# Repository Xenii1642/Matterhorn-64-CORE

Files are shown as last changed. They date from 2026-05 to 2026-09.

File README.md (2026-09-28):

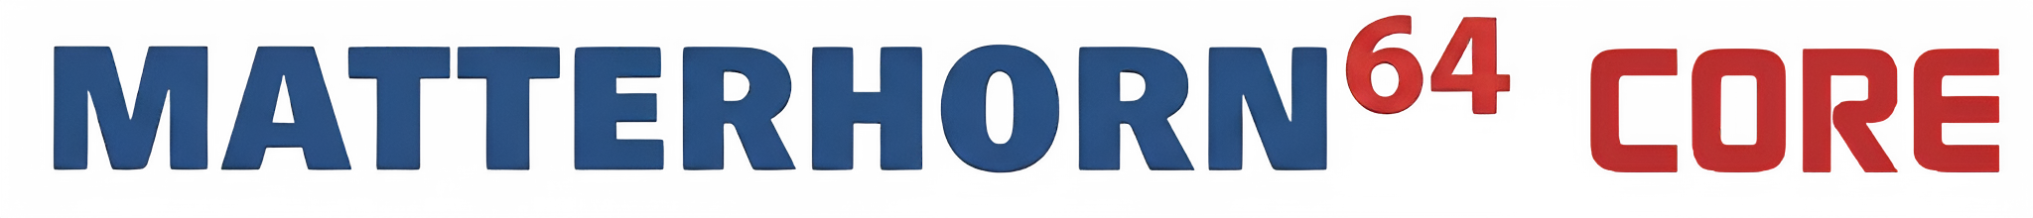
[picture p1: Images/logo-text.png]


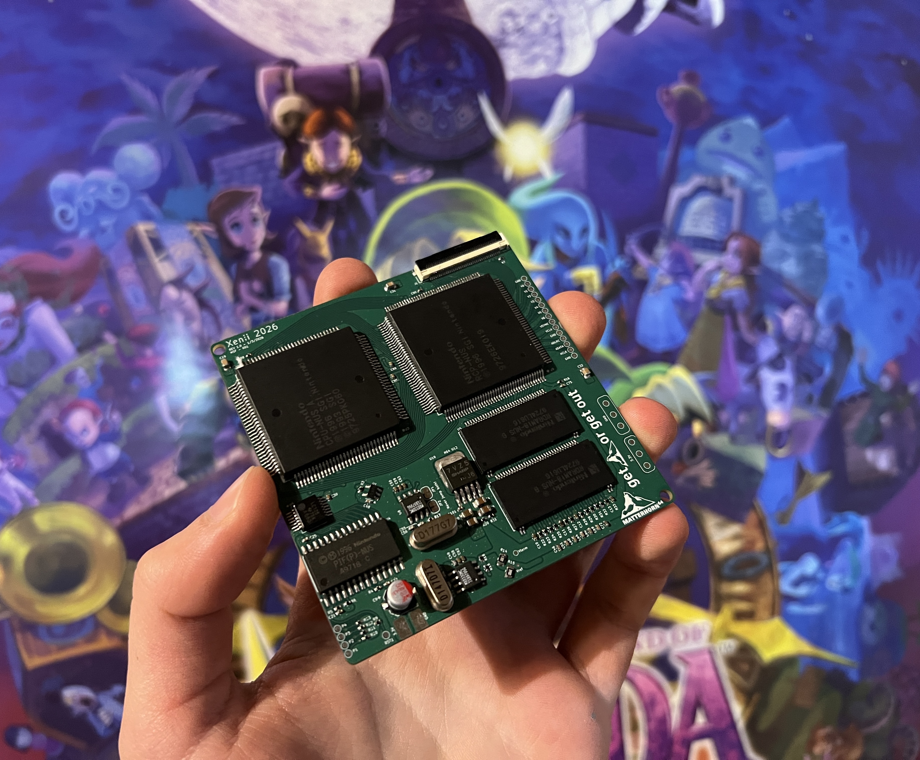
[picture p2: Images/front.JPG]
 
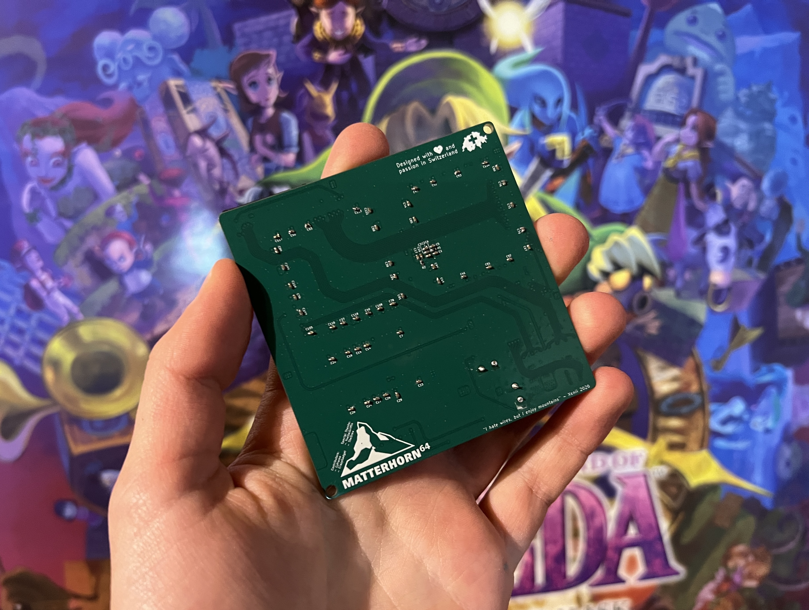
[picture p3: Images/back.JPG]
 



Matterhorn 64 CORE is the world's smallest open-source Nintendo 64 motherboard redesign. 
It utilizes components taken from an original Nintendo 64 console. 
Because it does **not** rely on emulation, it works perfectly with all games released on the system. 

This board redesign enables smaller, better, cleaner and more reliable Nintendo 64 based builds. 
Matterhorn 64 CORE can easily be integrated in different kinds of builds such as Nintendo 64 portable devices or mini consoles. 

It is fully open-source and released under the CERN-OHL-S-2.0 license. 

## Features
The Matterhorn 64 CORE redesign:
- The world's smallest open source Nintendo 64 motherboard
- Fits in a tiny 78x77.2 mm form factor 
- Runs on real hardware, **no emulation**
- 100% compatible with **all** games released on the system, including flashcarts
- Runs on 3.3V @2A 
- Designed using KiCad 9
- Layout and routing is optimized and clean, making it easy to use in future Nintendo 64 builds
- 100% open-source and released under the CERN-OHL-S-2.0 license

## Compatibility
### General compatibility
Due to the complexity of the Nintendo 64 hardware, some of its features are not available on this design. 
Please note that:
- The console is compatible with both NTSC and PAL components. However, it is **NOT** region free. It will only accept games released on the same region as the donor board.
- The console does accept memory expansion, but it is not natively compatible with the orignal Expansion Pak cartridge. You'll need to solder two RDRAM36 4MB instead of the two RDRAM18 2MB chips present by default on the console in order to enable the Expansion Pak.
- The console does **NOT** have any video output system. You'll either need to hook up an original composite encoder compatible with your region or an HDMI kit.
- The console does **NOT** have on-board voltage regulators. An additional N64 PSU or 3.3V PSU will be needed in order to use it. The console requires only requires 3.3V at 2A, but please consider that some HDMI mod or composite encoders may require 5V as well.
- The console is compatible with original controllers.
- It is also compatible with original cartridges using the breakout board.

### Nintendo 64 donor board revision compatibility
This mod is **ONLY** compatible with the following motherboard revisions:
#### NTSC Revisions (North America and Japan)
- NUS-CPU-01 (Japan only - 1996)
- NUS-CPU-02 (1996)
- NUS-CPU-03 (1996)
- NUS-CPU-04 (1996-1997)
- NUS-CPU-05 (1997)
- NUS-CPU-05-1 (1997)
- NUS-CPU-06 (1998)
- NUS-CPU-07 (1998)

#### PAL REVISION (Europe and Australia)
- NUS-CPU(P)-01 (1996)
- NUS-CPU(R)-01 (France only - 1997)

**ANY NEWER REVISION WILL NOT BE COMPATIBLE**

## Disclamer
This project requires complex soldering techniques. It relies on small pitch QFPs and 0402 passives.
Removing the components from the original board can cause irreparable damage if done incorrectly.

Due to the nature of this project, I am not responsible for any physical damages that may occur. 

## PCB Files
The Matterhorn 64 CORE motherboard has been entirely designed using KiCad 9. 
All the files are available in the [KiCad files folder](https://github.com/Xenii1642/Matterhorn-64-CORE/tree/main/KiCad%20Files) of this repository. 
The libraries created are also available in that same folder. 

Gerbers can be found in the [Gerber folder](https://github.com/Xenii1642/Matterhorn-64-CORE/tree/main/Gerbers). 

The console needs those two PCBs in order to make it work:
- [Matterhorn 64 CORE redesign](https://github.com/Xenii1642/Matterhorn-64-CORE/blob/main/Gerbers/Matterhorn-64-CORE.zip)
- [Matterhorn Cartridge Breakout](https://github.com/Xenii1642/Matterhorn-64-CORE/blob/main/Gerbers/Cartridge-Breakout-Board.zip)

The CORE itself represents the main logic of the console. The breakout board is used easily connect a full size game cartridge to the console. 

## Ordering
For this project, I recommend ordering the board through [JLCPCB](https://jlcpcb.com/) or [PCBWay](https://pcbway.com/). 
I personally ordered mine through [JLCPCB](https://jlcpcb.com/). 

You'll find here the list of settings that must be applied when ordering. 

### [Matterhorn 64 CORE](https://github.com/Xenii1642/Matterhorn-64-CORE/blob/main/Gerbers/Matterhorn-64-CORE.zip)
- Material: FR4
- Layers: 4
- Thickness: 1.6mm
- Specify Stackup: YES - JLC04161H-3313
- Impedance Control: ±10%
- Stencil: recommended but not obligatory.

### [Matterhorn Cartridge Breakout](https://github.com/Xenii1642/Matterhorn-64-CORE/blob/main/Gerbers/Cartridge-Breakout-Board.zip)
- Material: FR4
- Layers: 2

### Board Impedance Control
As you might notice, the CORE requires controlled impedance. 
The Nintendo 64 uses an extremely fast Rambus Dynamic Random Access Memory Bus (RDRAM BUS). 
In order to work, the CORE requires controlled impedance to match the 50Ω required by the RDRAM BUS. 

The Gerber files for this board include an Excel document which specifies which traces require those controlled impedance. 
This document will only be taken into account by JLCPCB if the order specifies the use of the "Controlled Impedance" option set to ±10%.

Please note that the board **might** work by using the 3313 stackup with no controlled impedance. 
To make sure my prototype was working, I did order it using those specifications. 
Ordering without it has not been tried and is at your own risks. 

All the components are listed in the Bill Of Materials (BOM). They can be ordered through Digikey or Mouser. 

## Assembly 
Once you've sourced a working Nintendo 64 console, a few games to test it, all the components and the Matterhorn 64 CORE boards, assembly can begin!
First of all, you'll need to access the Nintendo 64 motherboard and remove these components:
- CPU-NUS (U10)
- RCP-NUS (U9)
- 2x RDRAM18-NUS (U14 & U11) (or 1x RDRAM36 depending of the version, U14)) 
- NUS-PIF (U6)
- PTS9128 (U3)
- 74LCV125 (U8)
- 2x MX8330 (U7 & U15)
- 2x Crystals (X1 & X2)
- Sharp 7VZ5 LDO (U12)
- Cartridge slot (P5)

Source of this image: Wikipedia.com
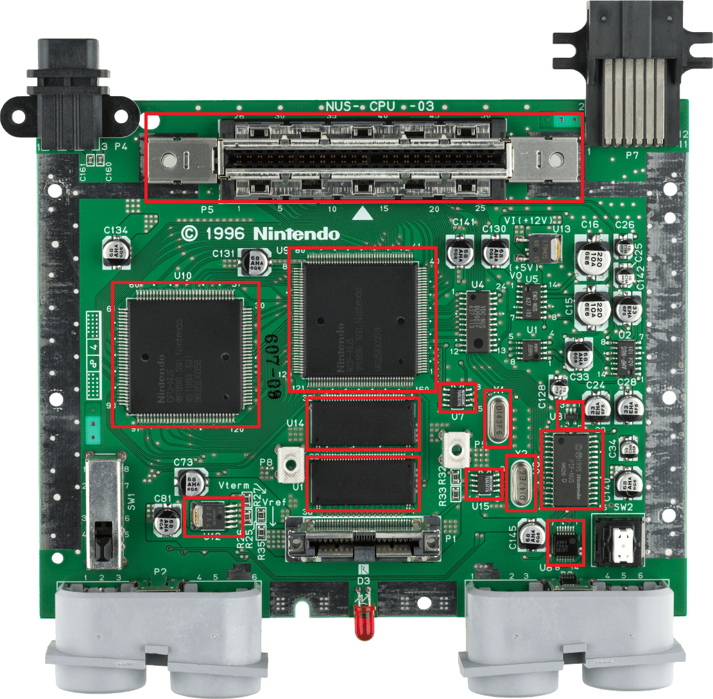
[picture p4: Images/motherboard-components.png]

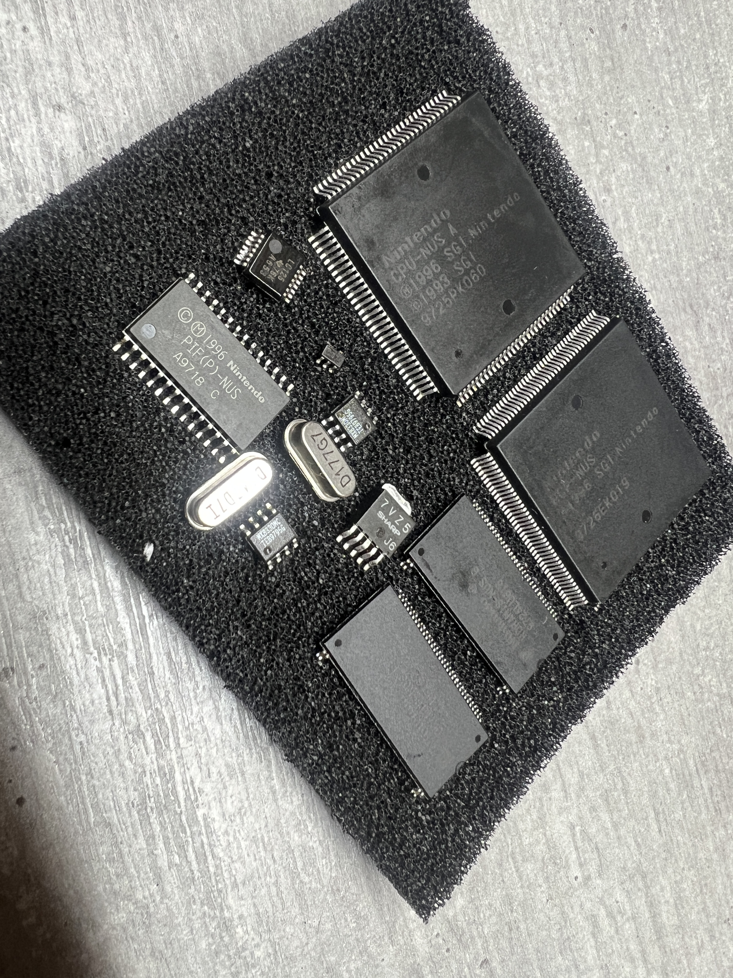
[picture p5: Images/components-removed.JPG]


I personally removed mine using hot air and a bit of flux. I heated at 360°C. 
Once removed, they can take place on the new motherboard. 
Low melting solder is not recommended in this process since the board will heat and cool down constantly when running, which can damage the solder joints after a long time. It is also not recommended to heat either the board or the components too much, which could lead to issues. 
I recommend soldering the whole front side and then solder the back side. 

The breakout board is much simpler, it only has a single FFC connector and the cartridge slot, which are much easier to solder than the little passives in my opinion. 

Once everything is done and cleaned using isopropyl alcohol, the test process can begin!

## Testing
First, connect the breakout board and make sure you don't have any dead shorts between the 3.3V line and the GND. 
Then, insert a game and power it up! The board is properly powered if:
- The console draws roughly 1.4A
- Vterm shows 2.55V
- Vref shows 1.91V

If you own a logic analyzer, you can connect it to the audio data pins or controller ports.
This is what you should see on the controller data line when a controller is plugged on Super Mario 64
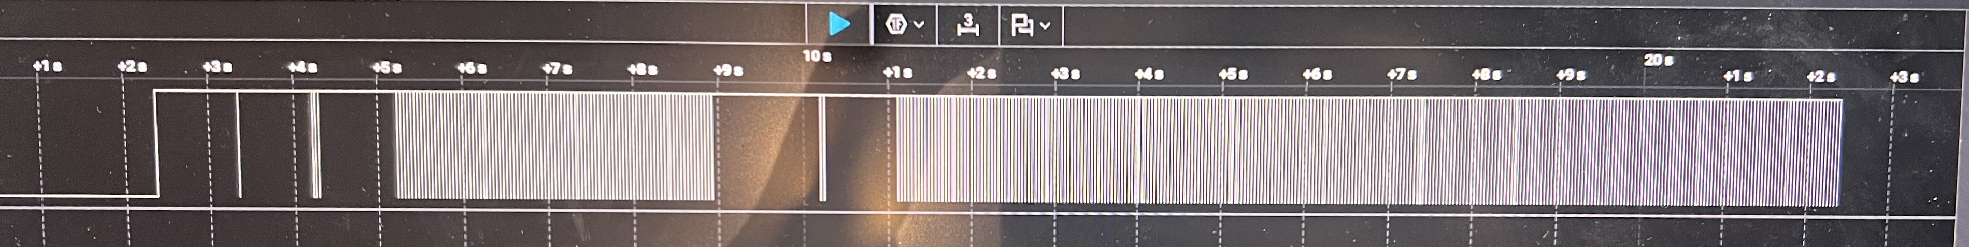
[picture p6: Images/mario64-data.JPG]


Please note that those signals **DO NOT** appear if the game is not properly read.
If everything seems good, you can hook up an HDMI mod or composite encoder and test it out! If it displays, it works! Great job!

## Known issue:
When I assembled my prototype, I *probably* heated the CPU too much while removing it. This caused the console to only work if heated.
More tests will be done to understand what exactly caused that. 

However I want to mention that the board works flawlessly for multiple consecutive days. 

## Future projects
This board is my official entry into Nintendo 64 modding. 
I'm working on two big projects which both use the CORE:
- Weisshorn 64 Mini: A collab between SenorAvocado and the Xii-Labs to create a Nintendo 64 Classic Mini console.
- Matterhorn 64: An ultimate Nintendo 64 portable. It's going to be a true revolution, also powered by the core.

Going to keep everyone update through my socials and the BitBuilt server. 

## Credits
This project was the most complicated I've done. Thankfully some members of the BitBuilt community helped me out to make my journey easier.
Therefore, I wanted to address big thanks to:
- @cy-888 who collaborated with me on some part of the design, especially footprints
- @CrazyGadgetMods who made great open-source flexes which helped me understanding some part of the console
- @mackieks who answered all my technical questions and took the time to review the whole board
- @thedrew and @gunnar who gave me insiparation to design my own motherboard recreation as long as helping me throughout the process.

## Media
You can find a video of my working board on my Instagram account:
[Matterhorn 64 CORE testing video](https://www.instagram.com/reel/DWvlAQKiPuf/)

I've also considered making a longer YouTube video on the subject. I will probably do it when I have more time.
## License
Matterhorn 64 CORE is released under the CERN-OHL-S-2.0 license. 
This license allows you to:
- Study
- Modify
- Manufacture
- Sell
- Distribute

Any modified versions of derivatives must also remain open-source under **the same, unmodified license**
You must also properly credit the original creators when reusing or redistributing these files.

## Support
If you notice anything wrong with the design, please let me know!
You can also reach to me for questions or general help, I'm always happy to help 👍

Thank you for your support and see you next time!

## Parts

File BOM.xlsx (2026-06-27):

Matterhorn 64 CORE BOM
CORE
Reference | Quantity | Value | Description | Manufacter Part Number | Link
C1,C2,C6,C17,C18,C19,C20 | 7 | 33µF | CAP TANT 33UF 10% 10V 1411 | TAJB336K010RNJ | https://www.digikey.com/en/products/detail/kyocera-avx/TAJB336K010RNJ/465808
C3,C12,C21,C23,C26,C27,C35, C38,C39,C41,C42,C43,C44,C45, C52,C53,C56,C57,C58,C61,C62, C70,C73,C80,C85,C86,C90,C92,C93 | 27 | 1µF | CAP CER 1UF 16V X5R 0402 | CL05A105KO5NNNC | https://www.digikey.com/en/products/detail/samsung-electro-mechanics/CL05A105KO5NNNC/3886725
C4,C5,C7,C8,C9,C11,C13,C25,C36, C37,C40,C47,C49,C50,C51,C54,C59, C60,C63,C64,C68,C69,C74,C75,C76, C77,C78,C79,C81,C82,C83,C87,C88, C89,C91,C94,C95,C96 | 38 | 0.1µF | CAP CER 0.1UF 25V X5R 0402 | CL05A104KA5NNNC | https://www.digikey.com/en/products/detail/samsung-electro-mechanics/CL05A104KA5NNNC/3886701
C10,C46,C48,C55,C71,C72,C84 | 7 | 0.01µF | CAP CER 10000PF 16V X7R 0402 | GRM155R71C103KA01D | https://www.digikey.com/en/products/detail/murata-electronics/GRM155R71C103KA01D/587215
C14 | 1 | 0.47µF | CAP CER 0.47UF 10V X5R 0402 | C0402X5R100-474KNE-CT | https://www.digikey.com/en/products/detail/venkel/C0402X5R100-474KNE-CT/14652959
C15,C16,C28,C34 | 4 | 38pF | CAP CER 39PF 50V C0G/NP0 0402 | C0402C390J5GACTU | https://www.digikey.com/en/products/detail/kemet/C0402C390J5GACTU/411020
C22 | 1 | 0.22µF | CAP CER 0.22UF 16V X7R 0402 | CL05B224KO5NNNC | https://www.digikey.com/en/products/detail/samsung-electro-mechanics/CL05B224KO5NNNC/3886834
C24 | 1 | 560pF | CAP CER 560PF 50V C0G/NP0 0402 | GRM1555C1H561JA01D | https://www.digikey.com/en/products/detail/murata-electronics/GRM1555C1H561JA01D/702503
C29 | 1 | 47µF | CAP ALUM 47UF 20% 6.3V SMD | UCL0J470MCL1GS | https://www.digikey.com/en/products/detail/nichicon/UCL0J470MCL1GS/2300235
C30,C31,C32,C33 | 4 | 3.3µF | CAP CER 3.3UF 4V X5R 0402 | C1005X5R0G335K050BB | https://www.digikey.com/en/products/detail/tdk-corporation/C1005X5R0G335K050BB/2443426
C65,C66 | 2 | 220pF | CAP CER 220PF 25V X7R 0402 | C0402X7R250-221KNE-CT | https://www.digikey.com/en/products/detail/venkel/C0402X7R250-221KNE-CT/14651555
C67 | 1 | 1nF | CAP CER 1000PF 50V X7R 0402 | C0402C102K5RACTU | https://www.digikey.com/en/products/detail/kemet/C0402C102K5RACTU/411034
J1 | 1 | 5051104091 | CONN FFC BOTTOM 40POS 0.5MM R/A | 5051104091 | https://www.digikey.com/en/products/detail/molex/5051104091/5254662
R1 | 1 | 1kΩ | RES 1K OHM 1% 1/16W 0402 | RC0402FR-131KL | https://www.digikey.com/en/products/detail/yageo/RC0402FR-131KL/13546623
R2,R8,R9,R27 | 4 | 47kΩ | RES 47K OHM 1% 1/16W 0402 | RC0402FR-0747KL | https://www.digikey.com/en/products/detail/yageo/RC0402FR-0747KL/726616
R3 | 1 | 24Ω 1% | RES 24 OHM 1% 1/16W 0402 | RC0402FR-0724RL | https://www.digikey.com/en/products/detail/yageo/RC0402FR-0724RL/5280933
R4 | 1 | 2kΩ | RES 2K OHM 5% 1/16W 0402 | RC0402JR-072KL | https://www.digikey.com/en/products/detail/yageo/RC0402JR-072KL/726434
R5 | 1 | 301Ω 1% | RES 301 OHM 1% 1/16W 0402 | RC0402FR-07301RL | https://www.digikey.com/en/products/detail/yageo/RC0402FR-07301RL/726591
R6 | 1 | 316Ω 1% | RES 316 OHM 1% 1/16W 0402 | RC0402FR-07316RL | https://www.digikey.com/en/products/detail/yageo/RC0402FR-07316RL/5280974
R7 | 1 | 5.12kΩ | RES 5.1K OHM 1% 1/16W 0402 | RC0402FR-135K1L | https://www.digikey.com/en/products/detail/yageo/RC0402FR-135K1L/14286364
R10 | 1 | 51kΩ | RES 51K OHM 5% 1/16W 0402 | RC0402JR-0751KL | https://www.digikey.com/en/products/detail/yageo/RC0402JR-0751KL/2827651
R11 | 1 | 150Ω 1% | RES 150 OHM 1% 1/16W 0402 | RC0402FR-13150RL | https://www.digikey.com/en/products/detail/yageo/RC0402FR-13150RL/13694105
R12,R25,R29,R30 | 4 | 750Ω | RES 750 OHM 1% 1/16W 0402 | RC0402FR-13750RL | https://www.digikey.com/en/products/detail/yageo/RC0402FR-13750RL/17021816
R13,R14,R15,R16,R17,R18,R19,R20, R21,R22,R23,R24 | 12 | 51Ω | RES 51 OHM 1% 1/16W 0402 | RC0402FR-0751RL | https://www.digikey.com/en/products/detail/yageo/RC0402FR-0751RL/726629
R26 | 1 | 130Ω 1% | RES 130 OHM 1% 1/8W 0805 | RC0805FR-07130RL | https://www.digikey.com/en/products/detail/yageo/RC0805FR-07130RL/727589
R28 | 1 | 33Ω 1% | RES 33 OHM 1% 1/16W 0402 | RC0402FR-0733RL | https://www.digikey.com/en/products/detail/yageo/RC0402FR-0733RL/726593
R31 | 1 | 390Ω 1% | RES 390 OHM 1% 1/8W 0805 | RC0805FR-07390RL | https://www.digikey.com/en/products/detail/yageo/RC0805FR-07390RL/727902
R32,R33 | 2 | 4.7Ω | RES 4.7 OHM 5% 1/16W 0402 | RC0402JR-074R7L | https://www.digikey.com/en/products/detail/yageo/RC0402JR-074R7L/726476
Cartridge Breakout Board
Reference | Quantity | Value | Description | Manufacter Part Number | Link
J1 | 1 |  | CONN FFC BOTTOM 40POS 0.5MM R/A | 5051104091 | https://www.digikey.com/en/products/detail/molex/5051104091/5254662
C1, C2 | 2 | 10µF | CAP CER 10UF 10V X5R 0402 | CL05A106MP5NUNC | https://www.digikey.com/en/products/detail/samsung-electro-mechanics/CL05A106MP5NUNC/3887108

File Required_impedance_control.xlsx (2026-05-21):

Name | Signal | Reference Layer | Impedance Type | Trace Width (mils) | Impedance trace to copper (mils) | Impedance(ohm)±10% | Position | Note
Rambus Dynamic RAM Data Traces TOP LAYER (RDRAM) TOP LAYER | L1 | L2 | Single Ended (Non Coplanar) | 6.16 mils (0.156464 mm) | - | 50 |  | Required stackup: JLC04161H-3313 All the selected layers (in white) require 50 Ohms of impedance. The TOP traces are single ended non coplanar, but the BOTTOM traces are coplanar. Feel free to reach out in case you need to confirm something. Thanks a lot!
Rambus Dynamic RAM Data Traces (RDRAM) BOTTOM LAYER | L4 | L3 | Single Ended (Coplanar) | 6.06 mils (0.1539 mm) | 11.81102 mils (0.3 mm) | 50
CCTLPGM | L1 | L2 | Single Ended (Coplanar) | 23.24 mils (0.5903 mm) | 11.81102 mils (0.3 mm) | 22 |  | This curved trace requires 22 Ohms of impedance.
Detailed RDRAM traces
Layer 1 |  |  | Layer 4 |  | Both Top and Bottom Layers

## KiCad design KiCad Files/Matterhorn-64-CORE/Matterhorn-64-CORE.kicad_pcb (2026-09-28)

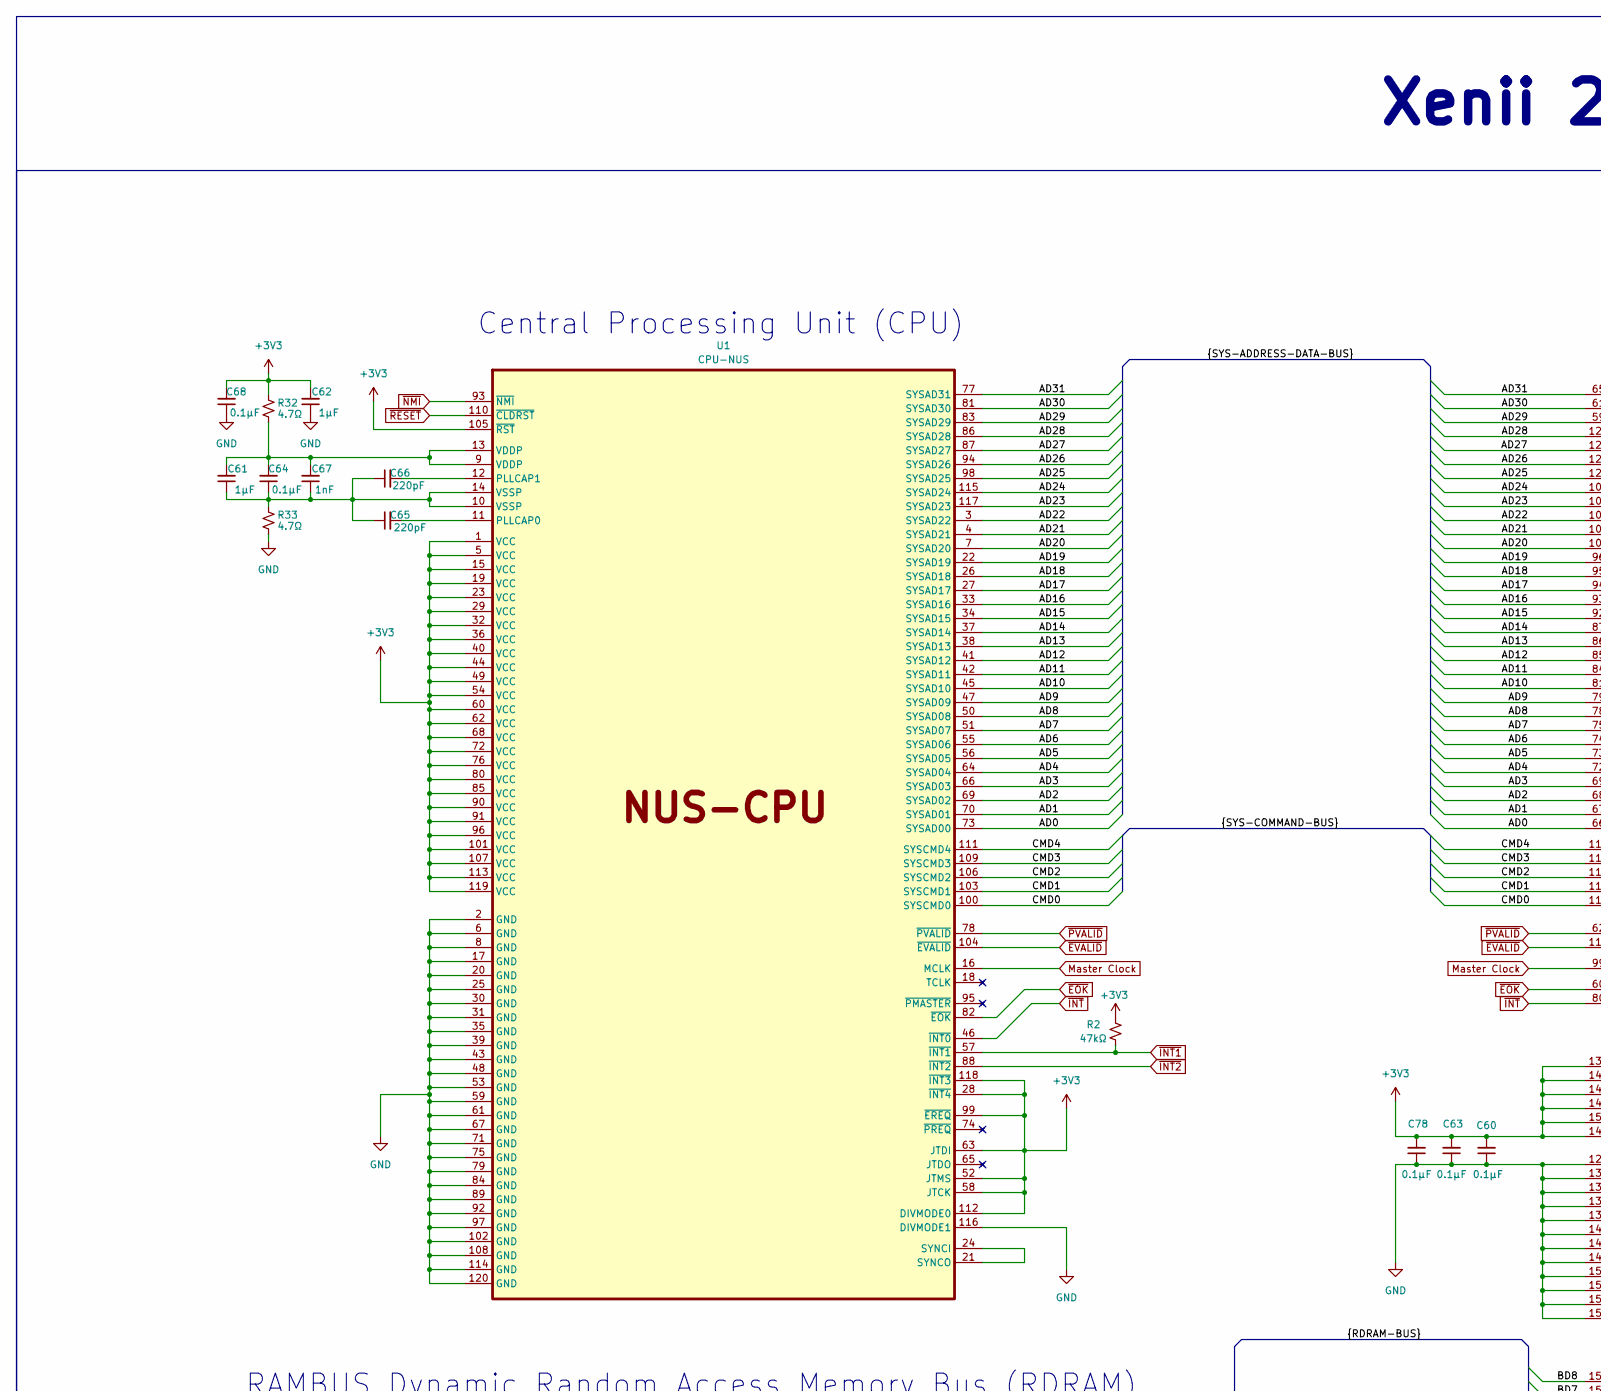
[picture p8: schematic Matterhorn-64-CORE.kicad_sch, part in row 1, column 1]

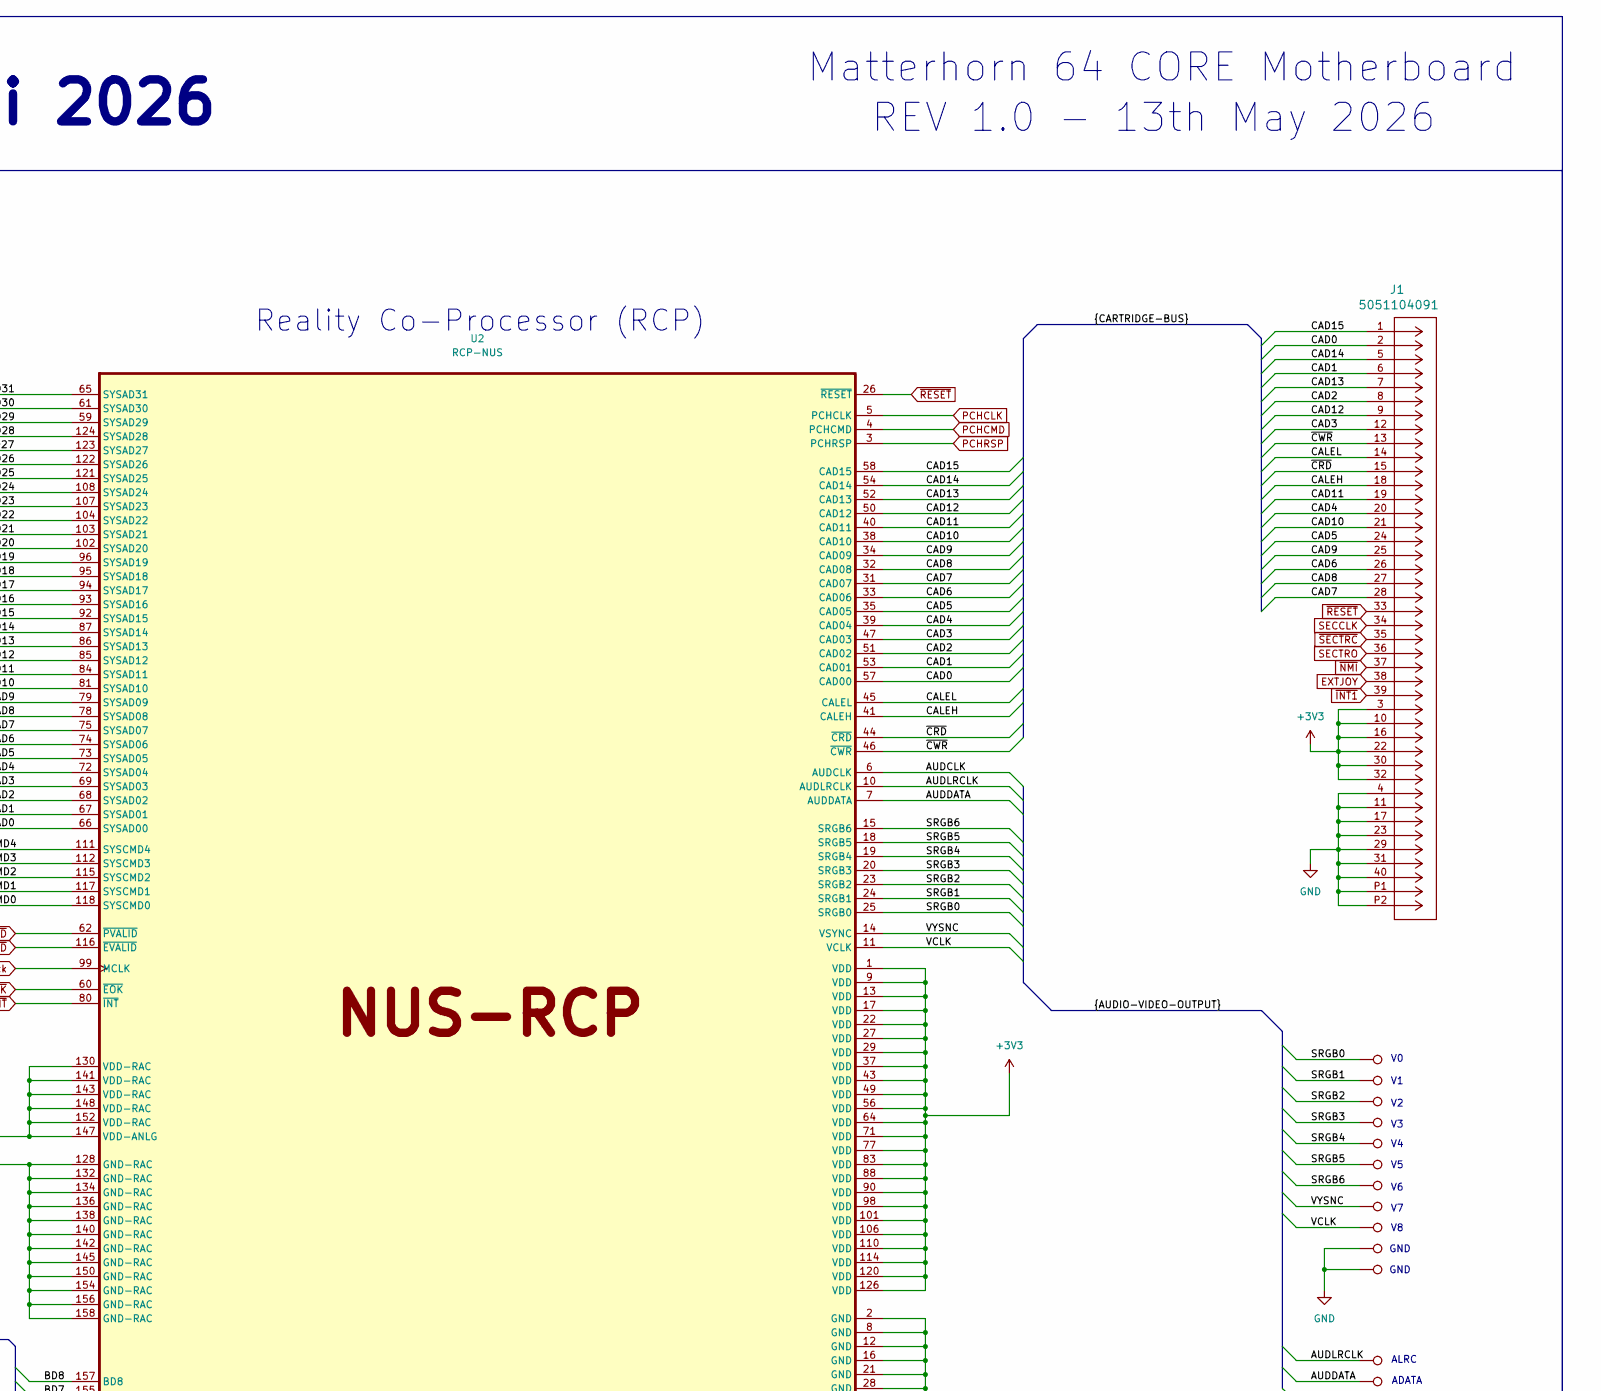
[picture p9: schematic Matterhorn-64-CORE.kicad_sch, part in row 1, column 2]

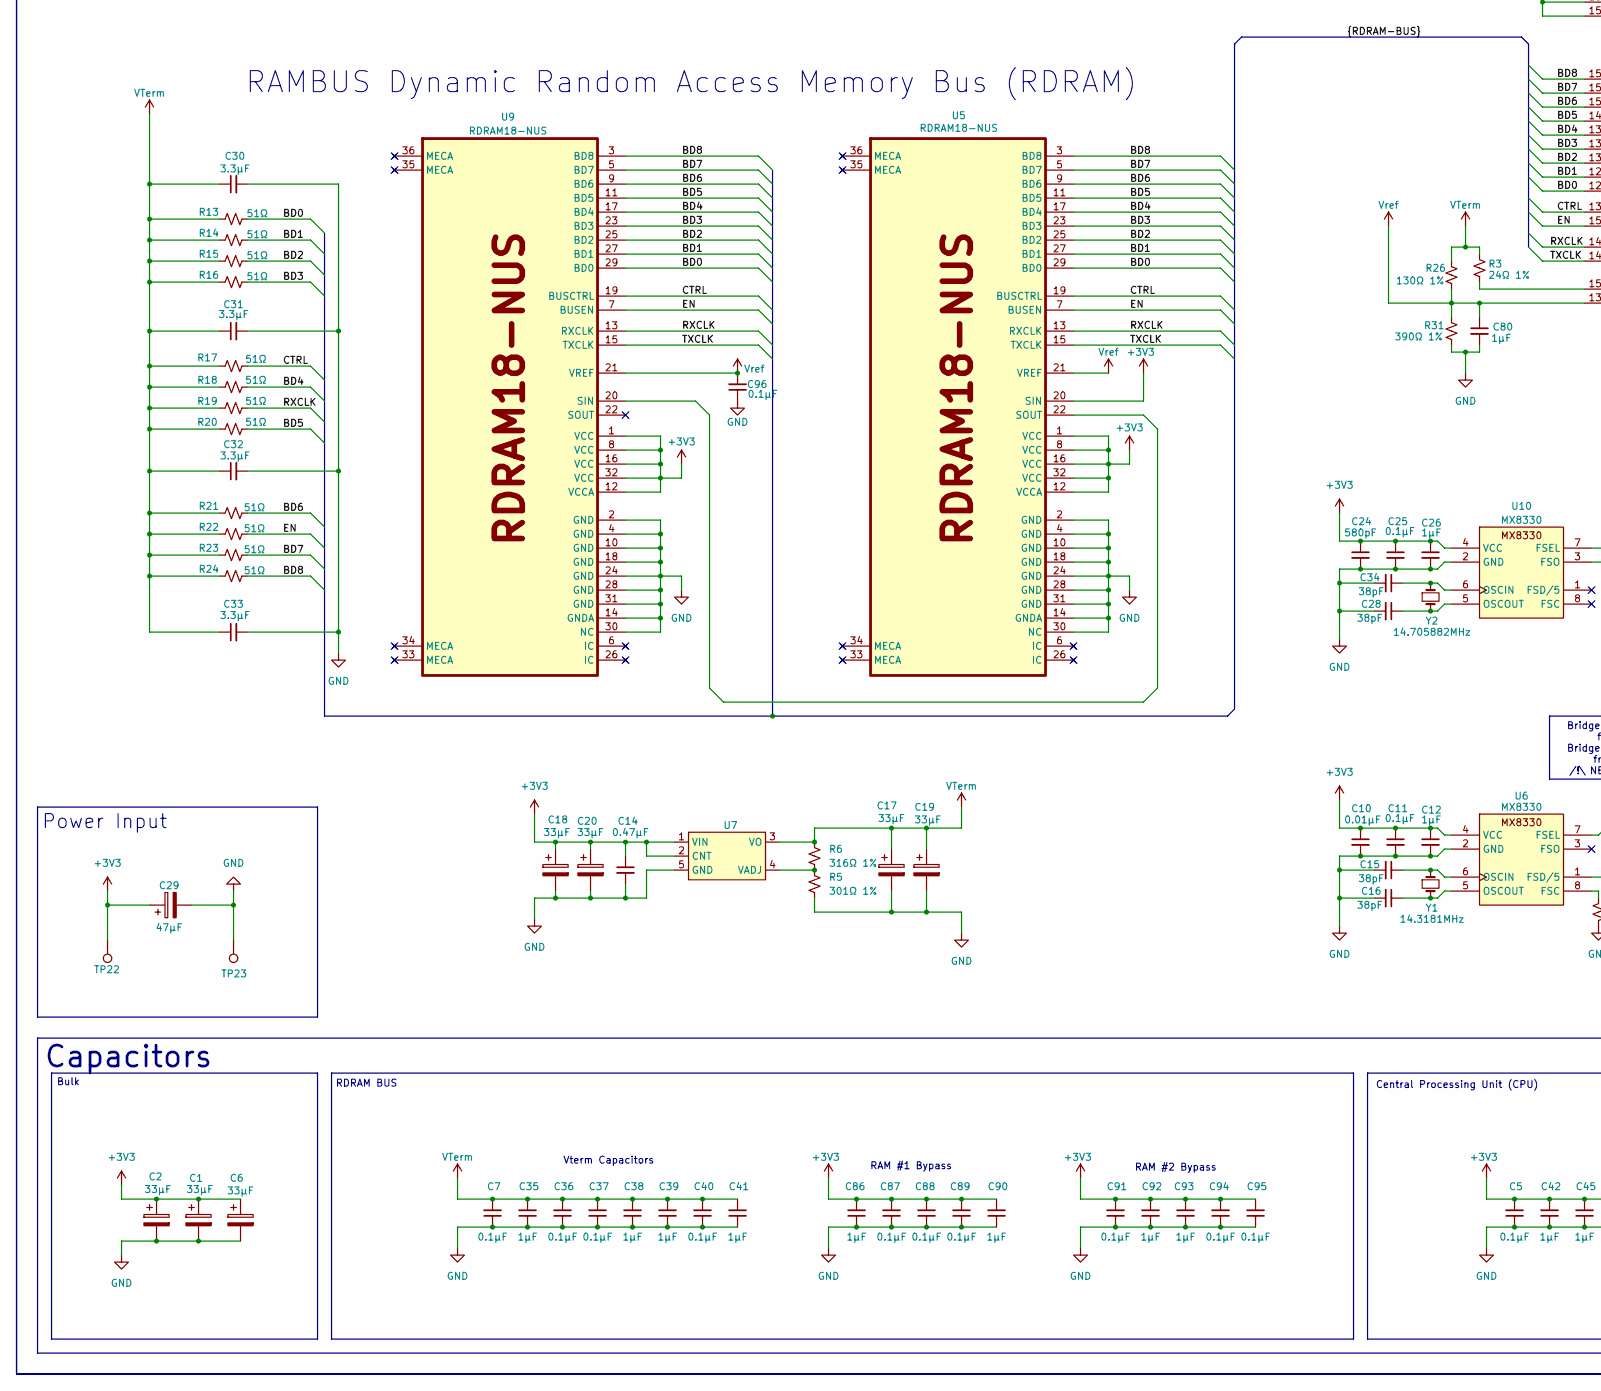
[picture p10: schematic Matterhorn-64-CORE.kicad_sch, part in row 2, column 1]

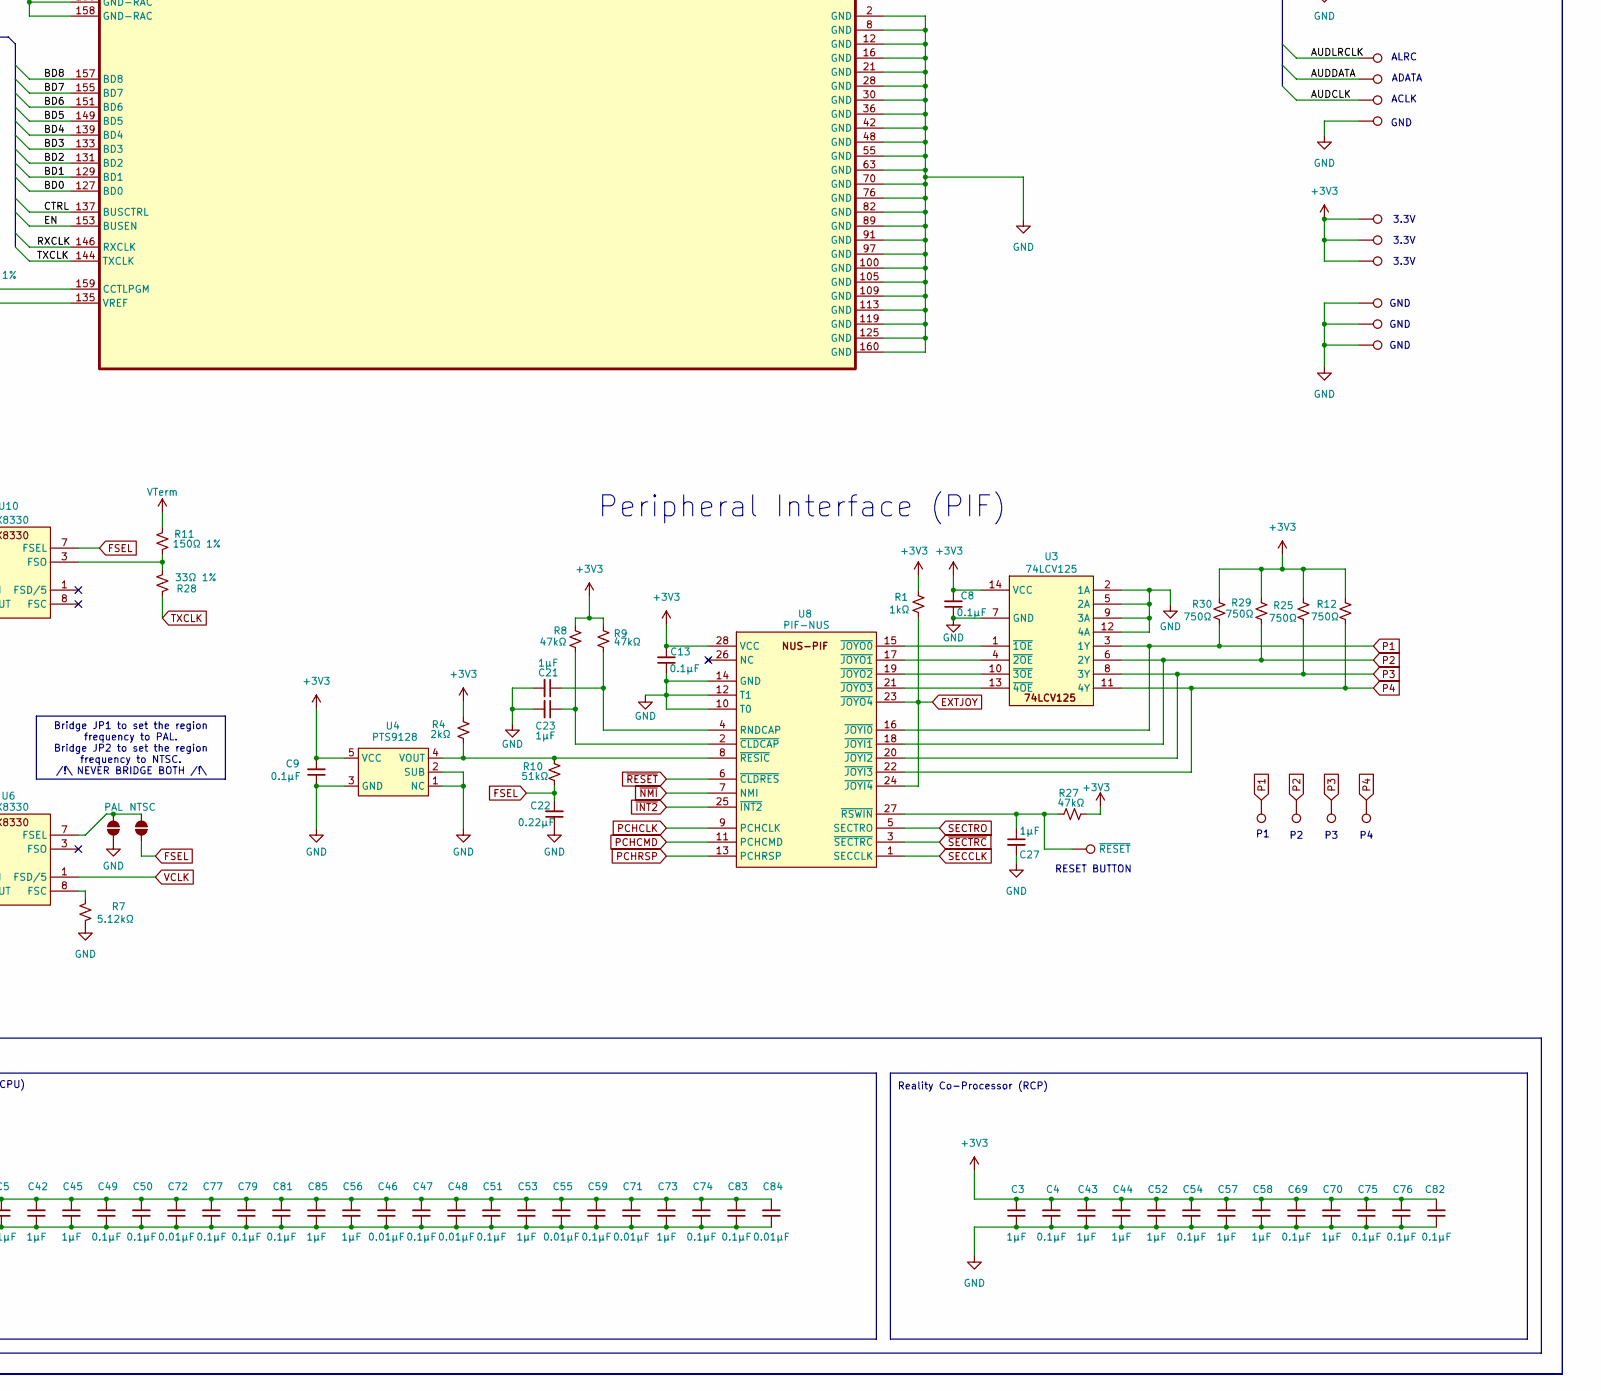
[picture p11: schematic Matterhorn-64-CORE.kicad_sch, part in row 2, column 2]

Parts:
C1, C2, C6, C17, C18, C19, C20: 33µF; TAJB_AVX-M
C3, C12, C21, C23, C26, C27, C35, C38, C39, C41, C42, C43, C44, C45, C52, C53, C56, C57, C58, C61, C62, C70, C73, C80, C85, C86, C90, C92, C93: 1µF; C_0402_1005Metric
C4, C5, C7, C8, C9, C11, C13, C25, C36, C37, C40, C47, C49, C50, C51, C54, C59, C60, C63, C64, C68, C69, C74, C75, C76, C77, C78, C79, C81, C82, C83, C87, C88, C89, C91, C94, C95, C96: 0.1µF; C_0402_1005Metric
C10, C46, C48, C55, C71, C72, C84: 0.01µF; C_0402_1005Metric
C14: 0.47µF; C_0402_1005Metric
C15, C16, C28, C34: 38pF; C_0402_1005Metric
C22: 0.22µF; C_0402_1005Metric
C24: 580pF; C_0402_1005Metric
C29: 47µF; 865080442004
C30, C31, C32, C33: 3.3µF; C_0402_1005Metric
C65, C66: 220pF; C_0402_1005Metric
C67: 1nF; C_0402_1005Metric
J1: 5051104091; CON_5051104091_MOL
NTSC: NTSC; SolderJumper-2_P1.3mm_Open_RoundedPad1.0x1.5mm
PAL: PAL; SolderJumper-2_P1.3mm_Open_RoundedPad1.0x1.5mm
R1: 1kΩ; R_0402_1005Metric
R2, R8, R9, R27: 47kΩ; R_0402_1005Metric
R3: 24Ω 1%; R_0402_1005Metric
R4: 2kΩ; R_0402_1005Metric
R5: 301Ω 1%; R_0402_1005Metric
R6: 316Ω 1%; R_0402_1005Metric
R7: 5.12kΩ; R_0402_1005Metric
R10: 51kΩ; R_0402_1005Metric
R11: 150Ω 1%; R_0402_1005Metric
R12, R25, R29, R30: 750Ω; R_0402_1005Metric
R13, R14, R15, R16, R17, R18, R19, R20, R21, R22, R23, R24: 51Ω; R_0402_1005Metric
R26: 130Ω 1%; R_0805_2012Metric
R28: 33Ω 1%; R_0402_1005Metric
R31: 390Ω 1%; R_0805_2012Metric
R32, R33: 4.7Ω; R_0402_1005Metric
RST1, RST2, RST3, RST4: TestPoint; TestPoint_Pad_D1.0mm
TP1, TP2, TP3, TP4, TP5, TP6, TP7, TP8, TP9, TP10, TP11, TP12, TP13, TP14, TP15, TP16, TP17, TP18, TP19, TP20, TP21: TestPoint; TestPoint_Pad_D1.0mm
TP22, TP23: TestPoint; PowerPad
U1: CPU-NUS
U2: RCP-NUS
U3: 74LCV125
U4: PTS9128; SOT-23-5
U5, U9: RDRAM18-NUS
U6, U10: MX8330
U7: SHARP 7VZ5
U8: PIF-NUS
Y1: 14.3181MHz; Crystal
Y2: 14.705882MHz; Crystal
~{RESET}: TestPoint; TestPoint_Pad_D1.0mm

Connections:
+3V3: C1.1, C2.1, C3.2, C4.2, C5.2, C6.1, C8.2, C9.2, C10.1, C11.1, C12.1, C13.2, C14.1, C18.1, C20.1, C24.1, C25.1, C26.1, C29.1, C42.2, C43.2, C44.2, C45.2, C46.2, C47.2, C48.2, C49.2, C50.2, C51.2, C52.2, C53.2, C54.2, C55.2, C56.2, C57.2, C58.2, C59.2, C60.2, C62.2, C63.2, C68.2, C69.2, C70.2, C71.2, C72.2, C73.2, C74.2, C75.2, C76.2, C77.2, C78.2, C79.2, C81.2, C82.2, C83.2, C84.2, C85.2, C86.2, C87.2, C88.2, C89.2, C90.2, C91.2, C92.2, C93.2, C94.2, C95.2, J1.3, J1.10, J1.16, J1.22, J1.30, J1.32, R1.1, R2.1, R4.2, R8.2, R9.2, R12.1, R25.1, R27.1, R29.1, R30.1, R32.1, TP19.1, TP20.1, TP21.1, TP22.1, U1.1 (VCC), U1.5 (VCC), U1.15 (VCC), U1.19 (VCC), U1.23 (VCC), U1.28 (~INT4), U1.29 (VCC), U1.32 (VCC), U1.36 (VCC), U1.40 (VCC), U1.44 (VCC), U1.49 (VCC), U1.52 (JTMS), U1.54 (VCC), U1.58 (JTCK), U1.60 (VCC), U1.62 (VCC), U1.63 (JTDI), U1.68 (VCC), U1.72 (VCC), U1.76 (VCC), U1.80 (VCC), U1.85 (VCC), U1.90 (VCC), U1.91 (VCC), U1.96 (VCC), U1.99 (~EREQ), U1.101 (VCC), U1.105 (~RST), U1.107 (VCC), U1.112 (DIVMODE0), U1.113 (VCC), U1.118 (~INT3), U1.119 (VCC), U2.1 (VDD), U2.9 (VDD), U2.13 (VDD), U2.17 (VDD), U2.22 (VDD), U2.27 (VDD), U2.29 (VDD), U2.37 (VDD), U2.43 (VDD), U2.49 (VDD), U2.56 (VDD), U2.64 (VDD), U2.71 (VDD), U2.77 (VDD), U2.83 (VDD), U2.88 (VDD), U2.90 (VDD), U2.98 (VDD), U2.101 (VDD), U2.106 (VDD), U2.110 (VDD), U2.114 (VDD), U2.120 (VDD), U2.126 (VDD), U2.130 (VDD-RAC), U2.141 (VDD-RAC), U2.143 (VDD-RAC), U2.147 (VDD-ANLG), U2.148 (VDD-RAC), U2.152 (VDD-RAC), U3.14 (VCC), U4.5 (VCC), U5.1 (VCC), U5.8 (VCC), U5.12 (VCCA), U5.16 (VCC), U5.20 (SIN), U5.32 (VCC), U6.4 (VCC), U7.1 (VIN), U7.2 (CNT), U8.28 (VCC), U9.1 (VCC), U9.8 (VCC), U9.12 (VCCA), U9.16 (VCC), U9.32 (VCC), U10.4 (VCC)
/AD0: U1.73 (SYSAD00), U2.66 (SYSAD00)
/AD1: U1.70 (SYSAD01), U2.67 (SYSAD01)
/AD2: U1.69 (SYSAD02), U2.68 (SYSAD02)
/AD3: U1.66 (SYSAD03), U2.69 (SYSAD03)
/AD4: U1.64 (SYSAD04), U2.72 (SYSAD04)
/AD5: U1.56 (SYSAD05), U2.73 (SYSAD05)
/AD6: U1.55 (SYSAD06), U2.74 (SYSAD06)
/AD7: U1.51 (SYSAD07), U2.75 (SYSAD07)
/AD8: U1.50 (SYSAD08), U2.78 (SYSAD08)
/AD9: U1.47 (SYSAD09), U2.79 (SYSAD09)
/AD10: U1.45 (SYSAD10), U2.81 (SYSAD10)
/AD11: U1.42 (SYSAD11), U2.84 (SYSAD11)
/AD12: U1.41 (SYSAD12), U2.85 (SYSAD12)
/AD13: U1.38 (SYSAD13), U2.86 (SYSAD13)
/AD14: U1.37 (SYSAD14), U2.87 (SYSAD14)
/AD15: U1.34 (SYSAD15), U2.92 (SYSAD15)
/AD16: U1.33 (SYSAD16), U2.93 (SYSAD16)
/AD17: U1.27 (SYSAD17), U2.94 (SYSAD17)
/AD18: U1.26 (SYSAD18), U2.95 (SYSAD18)
/AD19: U1.22 (SYSAD19), U2.96 (SYSAD19)
/AD20: U1.7 (SYSAD20), U2.102 (SYSAD20)
/AD21: U1.4 (SYSAD21), U2.103 (SYSAD21)
/AD22: U1.3 (SYSAD22), U2.104 (SYSAD22)
/AD23: U1.117 (SYSAD23), U2.107 (SYSAD23)
/AD24: U1.115 (SYSAD24), U2.108 (SYSAD24)
/AD25: U1.98 (SYSAD25), U2.121 (SYSAD25)
/AD26: U1.94 (SYSAD26), U2.122 (SYSAD26)
/AD27: U1.87 (SYSAD27), U2.123 (SYSAD27)
/AD28: U1.86 (SYSAD28), U2.124 (SYSAD28)
/AD29: U1.83 (SYSAD29), U2.59 (SYSAD29)
/AD30: U1.81 (SYSAD30), U2.61 (SYSAD30)
/AD31: U1.77 (SYSAD31), U2.65 (SYSAD31)
/AUDCLK: TP14.1, U2.6 (AUDCLK)
/AUDDATA: TP13.1, U2.7 (AUDDATA)
/AUDLRCLK: TP12.1, U2.10 (AUDLRCLK)
/BD0: R13.1, U2.127 (BD0), U5.29 (BD0), U9.29 (BD0)
/BD1: R14.1, U2.129 (BD1), U5.27 (BD1), U9.27 (BD1)
/BD2: R15.1, U2.131 (BD2), U5.25 (BD2), U9.25 (BD2)
/BD3: R16.1, U2.133 (BD3), U5.23 (BD3), U9.23 (BD3)
/BD4: R18.1, U2.139 (BD4), U5.17 (BD4), U9.17 (BD4)
/BD5: R20.1, U2.149 (BD5), U5.11 (BD5), U9.11 (BD5)
/BD6: R21.1, U2.151 (BD6), U5.9 (BD6), U9.9 (BD6)
/BD7: R23.1, U2.155 (BD7), U5.5 (BD7), U9.5 (BD7)
/BD8: R24.1, U2.157 (BD8), U5.3 (BD8), U9.3 (BD8)
/CAD0: J1.2, U2.57 (CAD00)
/CAD1: J1.6, U2.53 (CAD01)
/CAD2: J1.8, U2.51 (CAD02)
/CAD3: J1.12, U2.47 (CAD03)
/CAD4: J1.20, U2.39 (CAD04)
/CAD5: J1.24, U2.35 (CAD05)
/CAD6: J1.26, U2.33 (CAD06)
/CAD7: J1.28, U2.31 (CAD07)
/CAD8: J1.27, U2.32 (CAD08)
/CAD9: J1.25, U2.34 (CAD09)
/CAD10: J1.21, U2.38 (CAD10)
/CAD11: J1.19, U2.40 (CAD11)
/CAD12: J1.9, U2.50 (CAD12)
/CAD13: J1.7, U2.52 (CAD13)
/CAD14: J1.5, U2.54 (CAD14)
/CAD15: J1.1, U2.58 (CAD15)
/CALEH: J1.18, U2.41 (CALEH)
/CALEL: J1.14, U2.45 (CALEL)
/CMD0: U1.100 (SYSCMD0), U2.118 (SYSCMD0)
/CMD1: U1.103 (SYSCMD1), U2.117 (SYSCMD1)
/CMD2: U1.106 (SYSCMD2), U2.115 (SYSCMD2)
/CMD3: U1.109 (SYSCMD3), U2.112 (SYSCMD3)
/CMD4: U1.111 (SYSCMD4), U2.111 (SYSCMD4)
/CTRL: R17.1, U2.137 (BUSCTRL), U5.19 (BUSCTRL), U9.19 (BUSCTRL)
/EN: R22.1, U2.153 (BUSEN), U5.7 (BUSEN), U9.7 (BUSEN)
/RXCLK: R19.1, U2.146 (RXCLK), U5.13 (RXCLK), U9.13 (RXCLK)
/SRGB0: TP2.1, U2.25 (SRGB0)
/SRGB1: TP3.1, U2.24 (SRGB1)
/SRGB2: TP4.1, U2.23 (SRGB2)
/SRGB3: TP5.1, U2.20 (SRGB3)
/SRGB4: TP6.1, U2.19 (SRGB4)
/SRGB5: TP7.1, U2.18 (SRGB5)
/SRGB6: TP8.1, U2.15 (SRGB6)
/VYSNC: TP9.1, U2.14 (VSYNC)
/~CRD: J1.15, U2.44 (~CRD)
/~CWR: J1.13, U2.46 (~CWR)
EXTJOY: J1.38, R1.2, U8.23 (~JOYO4), U8.24 (~JOYI4)
FSEL: C22.2, NTSC.1 (A), R10.1, U10.7 (FSEL)
GND: C1.2, C2.2, C3.1, C4.1, C5.1, C6.2, C7.1, C8.1, C9.1, C10.2, C11.2, C12.2, C13.1, C14.2, C15.2, C16.2, C17.2, C18.2, C19.2, C20.2, C21.2, C22.1, C23.2, C24.2, C25.2, C26.2, C27.2, C28.2, C29.2, C30.2, C31.2, C32.2, C33.2, C34.2, C35.1, C36.1, C37.1, C38.1, C39.1, C40.1, C41.1, C42.1, C43.1, C44.1, C45.1, C46.1, C47.1, C48.1, C49.1, C50.1, C51.1, C52.1, C53.1, C54.1, C55.1, C56.1, C57.1, C58.1, C59.1, C60.1, C62.1, C63.1, C68.1, C69.1, C70.1, C71.1, C72.1, C73.1, C74.1, C75.1, C76.1, C77.1, C78.1, C79.1, C80.2, C81.1, C82.1, C83.1, C84.1, C85.1, C86.1, C87.1, C88.1, C89.1, C90.1, C91.1, C92.1, C93.1, C94.1, C95.1, C96.1, J1.4, J1.11, J1.17, J1.23, J1.29, J1.31, J1.40, J1.P1, J1.P2, PAL.1 (A), R5.2, R7.2, R31.1, R33.2, TP1.1, TP11.1, TP15.1, TP16.1, TP17.1, TP18.1, TP23.1, U1.2 (GND), U1.6 (GND), U1.8 (GND), U1.17 (GND), U1.20 (GND), U1.25 (GND), U1.30 (GND), U1.31 (GND), U1.35 (GND), U1.39 (GND), U1.43 (GND), U1.48 (GND), U1.53 (GND), U1.59 (GND), U1.61 (GND), U1.67 (GND), U1.71 (GND), U1.75 (GND), U1.79 (GND), U1.84 (GND), U1.89 (GND), U1.92 (GND), U1.97 (GND), U1.102 (GND), U1.108 (GND), U1.114 (GND), U1.116 (DIVMODE1), U1.120 (GND), U2.2 (GND), U2.8 (GND), U2.12 (GND), U2.16 (GND), U2.21 (GND), U2.28 (GND), U2.30 (GND), U2.36 (GND), U2.42 (GND), U2.48 (GND), U2.55 (GND), U2.63 (GND), U2.70 (GND), U2.76 (GND), U2.82 (GND), U2.89 (GND), U2.91 (GND), U2.97 (GND), U2.100 (GND), U2.105 (GND), U2.109 (GND), U2.113 (GND), U2.119 (GND), U2.125 (GND), U2.128 (GND-RAC), U2.132 (GND-RAC), U2.134 (GND-RAC), U2.136 (GND-RAC), U2.138 (GND-RAC), U2.140 (GND-RAC), U2.142 (GND-RAC), U2.145 (GND-RAC), U2.150 (GND-RAC), U2.154 (GND-RAC), U2.156 (GND-RAC), U2.158 (GND-RAC), U2.160 (GND), U3.2 (1A), U3.5 (2A), U3.7 (GND), U3.9 (3A), U3.12 (4A), U4.1 (NC), U4.2 (SUB), U4.3 (GND), U5.2 (GND), U5.4 (GND), U5.10 (GND), U5.14 (GNDA), U5.18 (GND), U5.24 (GND), U5.28 (GND), U5.30 (NC), U5.31 (GND), U6.2 (GND), U7.5 (GND), U8.10 (T0), U8.12 (T1), U8.14 (GND), U9.2 (GND), U9.4 (GND), U9.10 (GND), U9.14 (GNDA), U9.18 (GND), U9.24 (GND), U9.28 (GND), U9.30 (NC), U9.31 (GND), U10.2 (GND)
Master Clock: U1.16 (MCLK), U2.99 (MCLK)
unnamed: C61.1, C64.1, C65.1, C66.1, C67.1, R33.1, U1.10 (VSSP), U1.14 (VSSP)
unnamed: C61.2, C64.2, C67.2, R32.2, U1.9 (VDDP), U1.13 (VDDP)
unnamed: NTSC.2 (B), PAL.2 (B), U6.7 (FSEL)
unnamed: C65.2, U1.11 (PLLCAP0)
unnamed: C66.2, U1.12 (PLLCAP1)
unnamed: U1.21 (SYNCO), U1.24 (SYNCI)
unnamed: R3.1, U2.159 (CCTLPGM)
unnamed: U3.1 (~1OE), U8.15 (~JOYO0)
unnamed: U3.4 (~2OE), U8.17 (~JOYO1)
unnamed: U3.10 (~3OE), U8.19 (~JOYO2)
unnamed: U3.13 (~4OE), U8.21 (~JOYO3)
unnamed: R4.1, R10.2, U4.4 (VOUT), U8.8 (~RESIC)
unnamed: U5.22 (SOUT), U9.20 (SIN)
unnamed: R7.1, U6.8 (FSC)
unnamed: C15.1, U6.6 (OSCIN), Y1.1
unnamed: C16.1, U6.5 (OSCOUT), Y1.2
unnamed: R5.1, R6.2, U7.4 (VADJ)
unnamed: C21.1, R9.1, U8.4 (RNDCAP)
unnamed: C23.1, R8.1, U8.2 (~CLDCAP)
unnamed: C27.1, R27.2, U8.27 (~RSWIN), ~{RESET}.1
unnamed: R11.2, R28.1, U10.3 (FSO)
unnamed: C34.1, U10.6 (OSCIN), Y2.1
unnamed: C28.1, U10.5 (OSCOUT), Y2.2
P1: R30.2, RST4.1, U3.3 (1Y), U8.16 (~JOYI0)
P2: R29.2, RST3.1, U3.6 (2Y), U8.18 (~JOYI1)
P3: R25.2, RST2.1, U3.8 (3Y), U8.20 (~JOYI2)
P4: R12.2, RST1.1, U3.11 (4Y), U8.22 (~JOYI3)
PCHCLK: U2.5 (PCHCLK), U8.9 (PCHCLK)
PCHCMD: U2.4 (PCHCMD), U8.11 (PCHCMD)
PCHRSP: U2.3 (PCHRSP), U8.13 (PCHRSP)
SECCLK: J1.34, U8.1 (SECCLK)
SECTRO: J1.36, U8.5 (SECTRO)
TXCLK: R28.2, U2.144 (TXCLK), U5.15 (TXCLK), U9.15 (TXCLK)
VCLK: TP10.1, U2.11 (VCLK), U6.1 (FSD/5)
VTerm: C7.2, C17.1, C19.1, C30.1, C31.1, C32.1, C33.1, C35.2, C36.2, C37.2, C38.2, C39.2, C40.2, C41.2, R3.2, R6.1, R11.1, R13.2, R14.2, R15.2, R16.2, R17.2, R18.2, R19.2, R20.2, R21.2, R22.2, R23.2, R24.2, R26.2, U7.3 (VO)
Vref: C80.1, C96.2, R26.1, R31.2, U2.135 (VREF), U5.21 (VREF), U9.21 (VREF)
~EOK: U1.82 (~EOK), U2.60 (~EOK)
~EVALID: U1.104 (~EVALID), U2.116 (~EVALID)
~INT1: J1.39, R2.2, U1.57 (~INT1)
~INT2: U1.88 (~INT2), U8.25 (~INT2)
~INT: U1.46 (~INT0), U2.80 (~INT)
~NMI: J1.37, U1.93 (~NMI), U8.7 (NMI)
~PVALID: U1.78 (~PVALID), U2.62 (~PVALID)
~RESET: J1.33, U1.110 (~CLDRST), U2.26 (~RESET), U8.6 (~CLDRES)
~SECTRC: J1.35, U8.3 (~SECTRC)

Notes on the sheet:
Reality Co-Processor (RCP)
RESET BUTTON
GND
ALRC
Bulk
3.3V
RAM #1 Bypass
RAMBUS Dynamic Random Access Memory Bus (RDRAM)
ADATA
Peripheral Interface (PIF)
Capacitors
Central Processing Unit (CPU)
RAM #2 Bypass
ACLK
Power Input
RDRAM BUS
Vterm Capacitors
Matterhorn 64 CORE Motherboard
REV 1.0 - 13th May 2026
Xenii 2026
Bridge JP1 to set the region frequency to PAL. Bridge JP2 to set the region frequency to NTSC. /!\ NEVER BRIDGE BOTH /!\

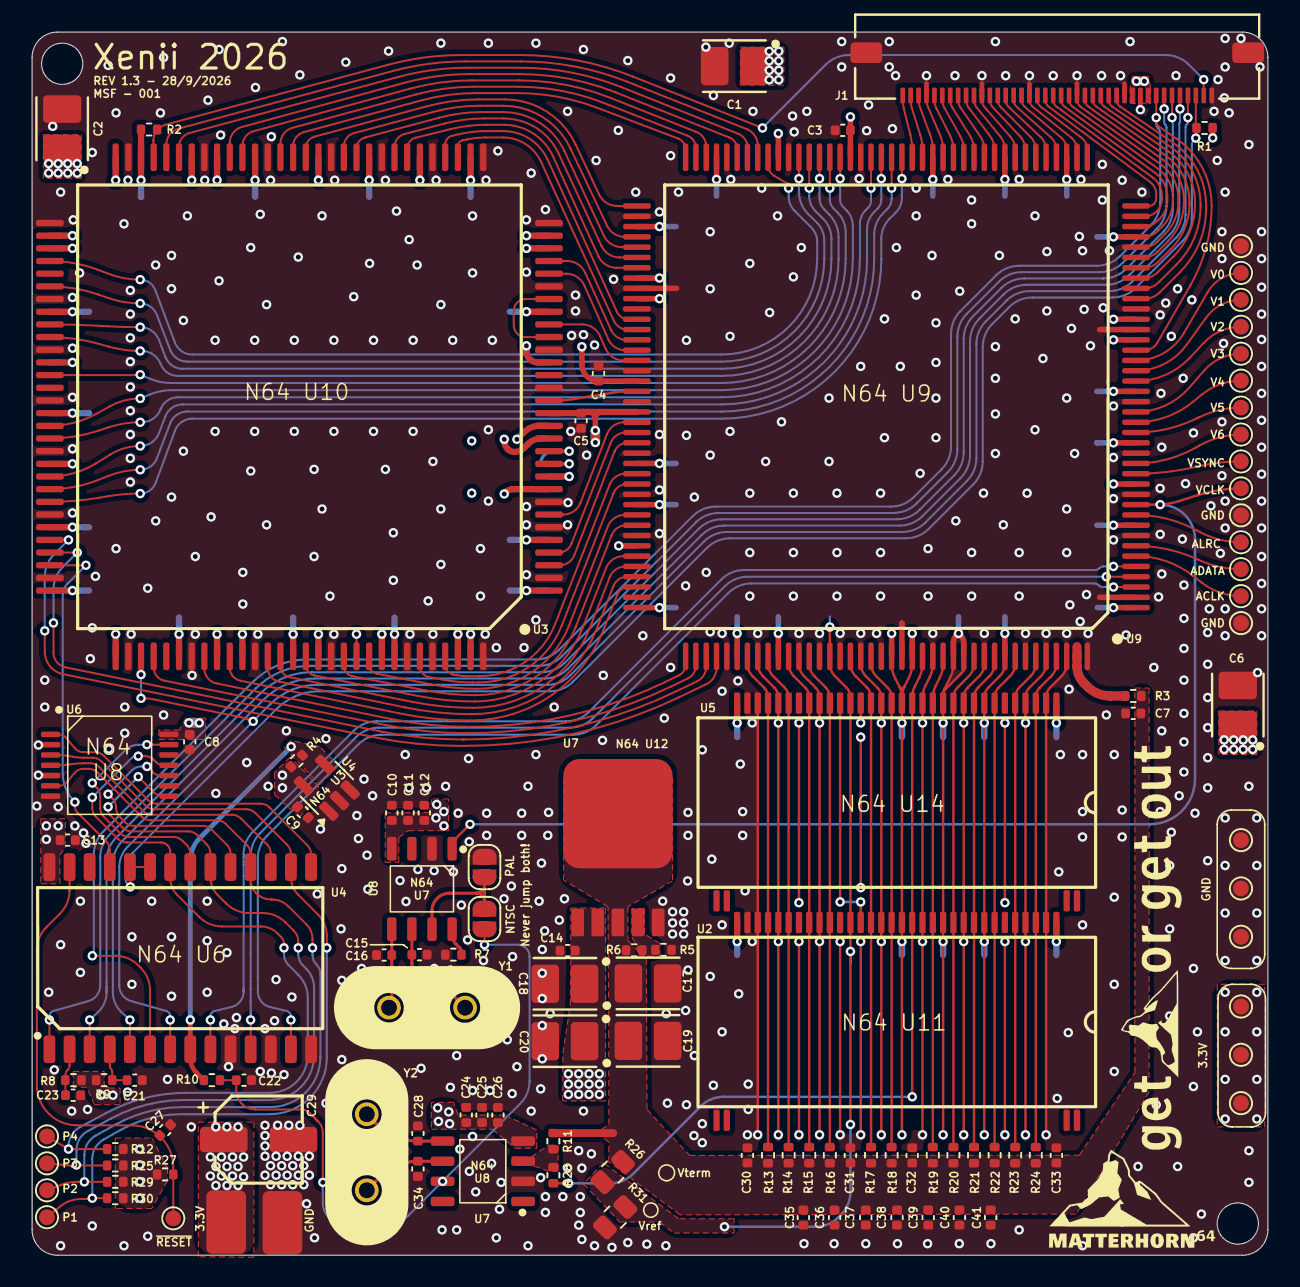
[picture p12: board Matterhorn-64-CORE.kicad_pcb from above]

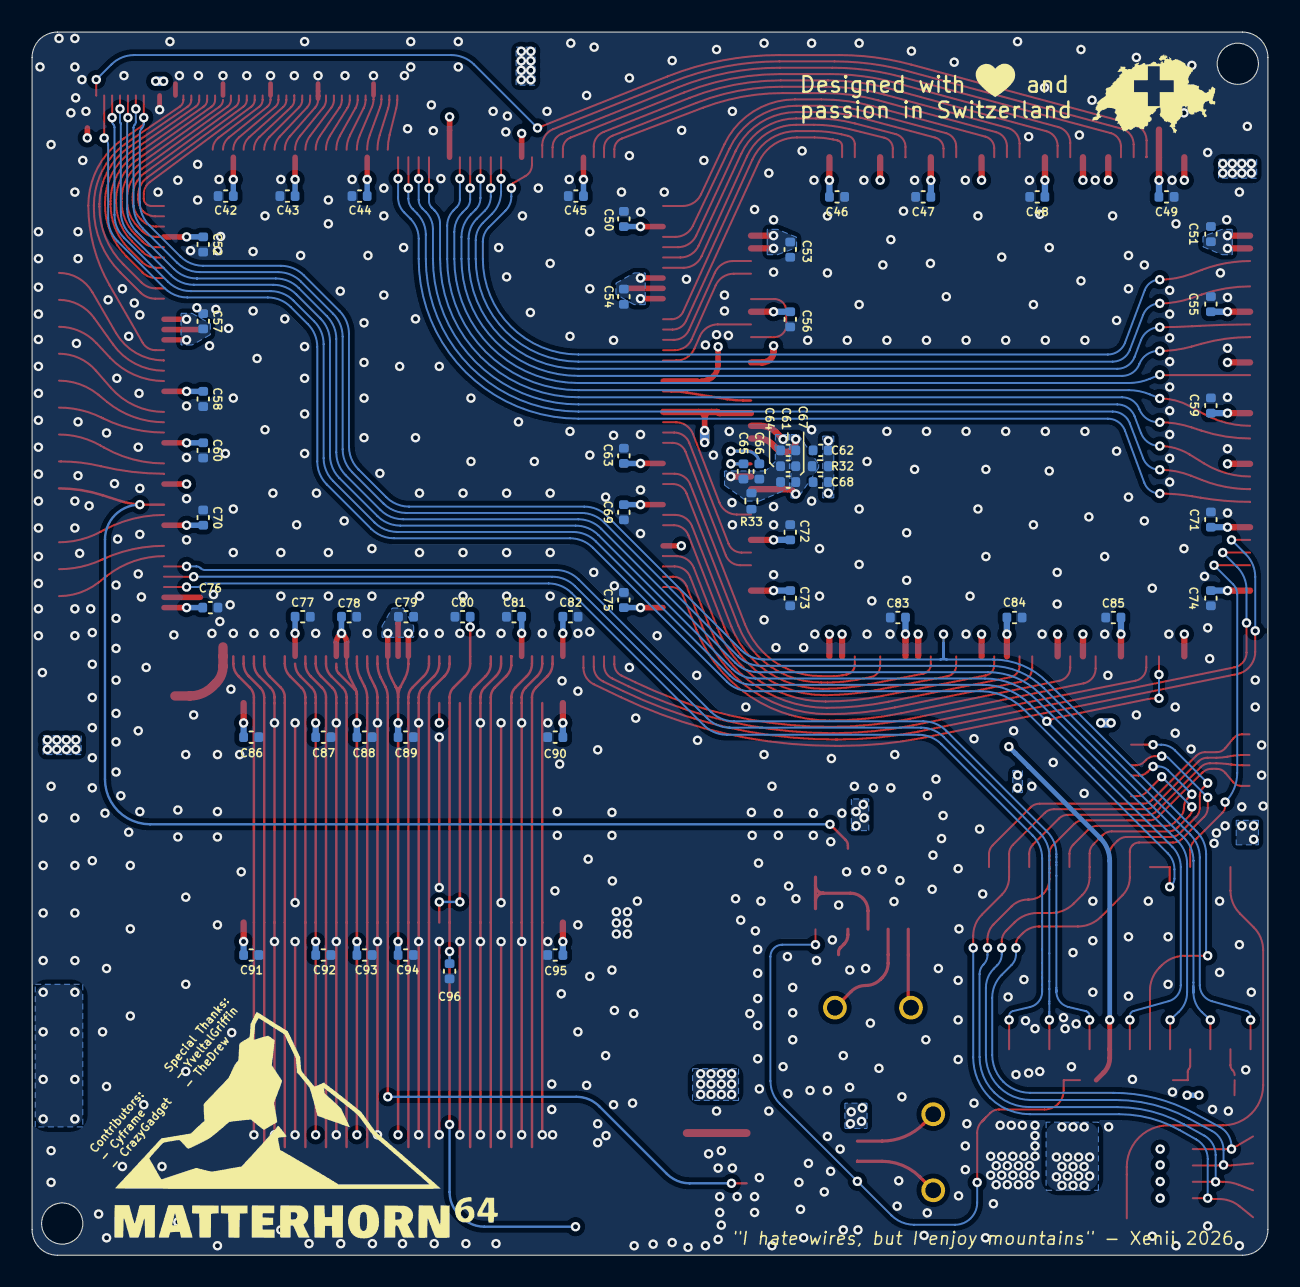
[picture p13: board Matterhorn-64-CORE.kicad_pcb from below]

Board: 4 copper layers, 78.0 x 77.2 mm, 171 parts (57 on the bottom side), 130 nets.

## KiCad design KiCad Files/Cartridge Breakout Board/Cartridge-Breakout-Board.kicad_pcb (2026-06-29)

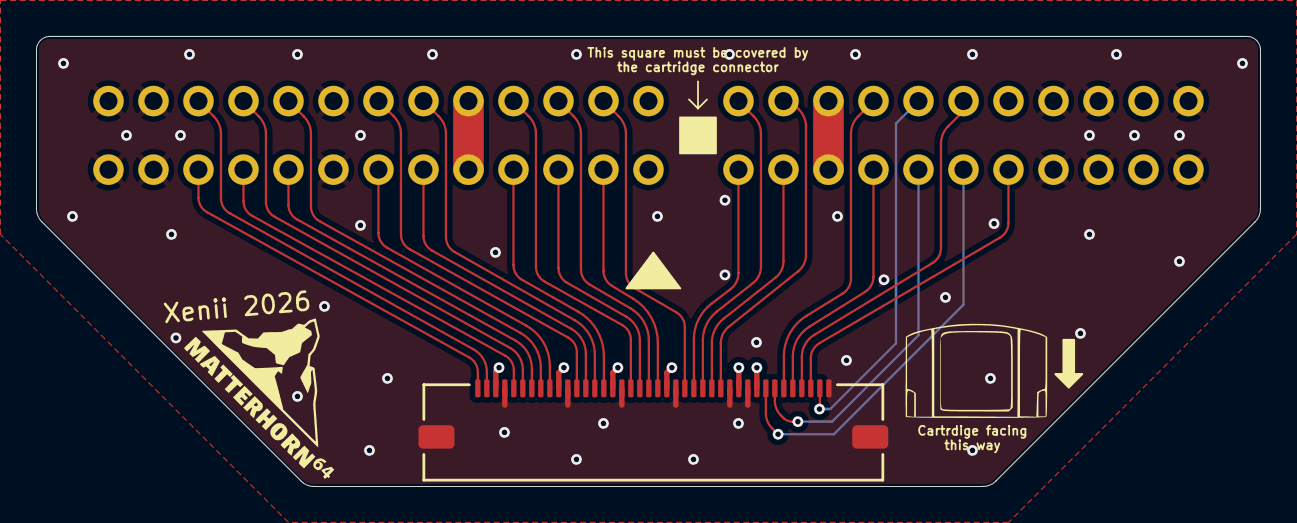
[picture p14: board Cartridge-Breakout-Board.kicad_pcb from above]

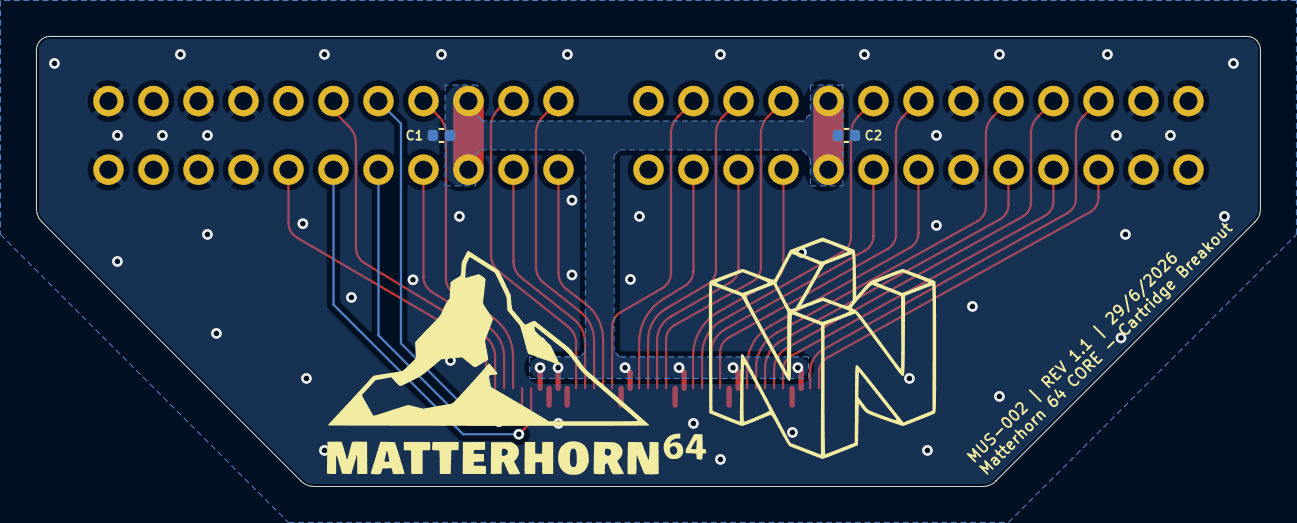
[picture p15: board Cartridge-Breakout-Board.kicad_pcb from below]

Board: 2 copper layers, 68.0 x 25.0 mm, 4 parts (2 on the bottom side), 29 nets.

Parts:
C1, C2: 10µF; C_0402_1005Metric
J1: CON_5051104091_MOL
U1: cartridge-slot

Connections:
+3V3: C1.1, C2.1, J1.9, J1.11, J1.19, J1.25, J1.31, J1.38, U1.9 (VCC), U1.17 (VCC), U1.34 (VCC), U1.42 (VCC)
/CAD0: J1.39, U1.28 (AD0)
/CAD1: J1.35, U1.29 (AD1)
/CAD2: J1.33, U1.30 (AD2)
/CAD3: J1.29, U1.32 (AD3)
/CAD4: J1.21, U1.36 (AD4)
/CAD5: J1.17, U1.37 (AD5)
/CAD6: J1.15, U1.40 (AD6)
/CAD7: J1.13, U1.41 (AD7)
/CAD8: J1.14, U1.16 (AD8)
/CAD9: J1.16, U1.15 (AD9)
/CAD10: J1.20, U1.12 (AD10)
/CAD11: J1.22, U1.11 (AD11)
/CAD12: J1.32, U1.7 (AD12)
/CAD13: J1.34, U1.5 (AD13)
/CAD14: J1.36, U1.4 (AD14)
/CAD15: J1.40, U1.3 (AD15)
/CALEH: J1.23, U1.35 (ALEH)
/CALEL: J1.27, U1.33 (ALEL)
/~CRD: J1.26, U1.10 (~RD)
/~CWR: J1.28, U1.8 (~WR)
EXTJOY: J1.3, U1.21 (EXTJOY)
GND: C1.2, C2.2, J1.1, J1.10, J1.12, J1.18, J1.24, J1.30, J1.37, J1.P1, J1.P2, U1.1 (GND), U1.2 (GND), U1.6 (GND), U1.22 (GND), U1.23 (GND), U1.25 (GND), U1.26 (GND), U1.27 (GND), U1.31 (GND), U1.47 (GND), U1.48 (GND), U1.50 (GND)
SECCLK: J1.7, U1.19 (SECCLK)
SECTRO: J1.5, U1.18 (SEC1)
~INT: J1.2, U1.44 (~INT)
~NMI: J1.4, U1.45 (~RESTART)
~RESET: J1.8, U1.20 (~RESET)
~SECTRC: J1.6, U1.43 (SEC2)

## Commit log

2026-05-14 Fix PCB links and update contributor names
    Updated PCB links and credit names in README.
2026-05-16 Adjusted RDRAM bottom traces
2026-05-16 Additionnal details for RDRAM controlled impedance
    [Required_impedance_control.xlsx]
2026-06-29 Updated the cartridge breakout board to REV 1.1
    Changes the cartridge connector which didn't have the correct pitch.
    [Cartridge-Breakout-Board.kicad_pcb]
2026-06-29 Updated to REV 1.1
    Changes the cartridge connector for the correct pitch.
2026-06-29 Fixes some mistakes in the footprint library.
    - Corrected the cartridge slot connector with the correct pitch (used by the breakout board REV 1.1)
    - Corrected the pins' numeration of the 74HC125.
2026-07-03 Updates some silkscreen issues
    [Matterhorn-64-CORE.kicad_pcb]
2026-09-28 Fixes a little silkscreen issue (R28 placement)
